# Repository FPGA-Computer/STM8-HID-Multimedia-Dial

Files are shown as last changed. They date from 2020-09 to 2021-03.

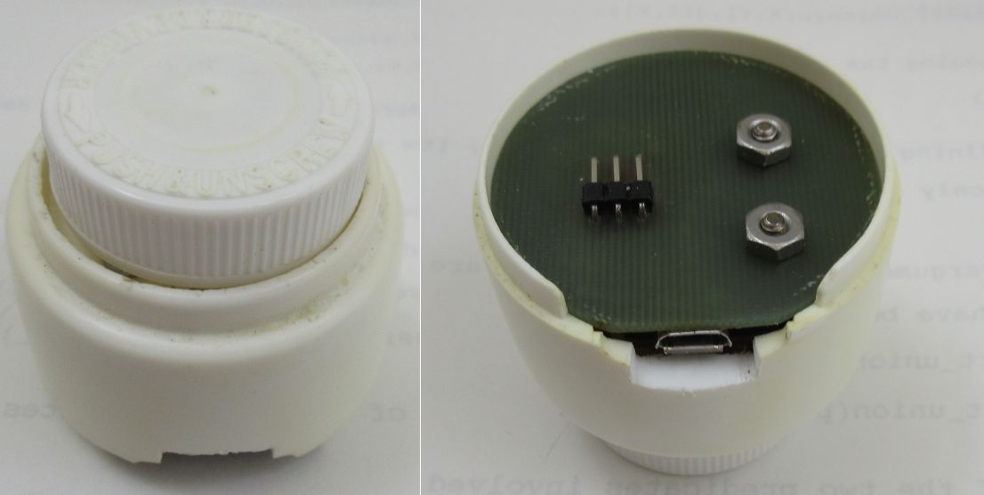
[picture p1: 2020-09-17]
hardware/Assembled.jpg

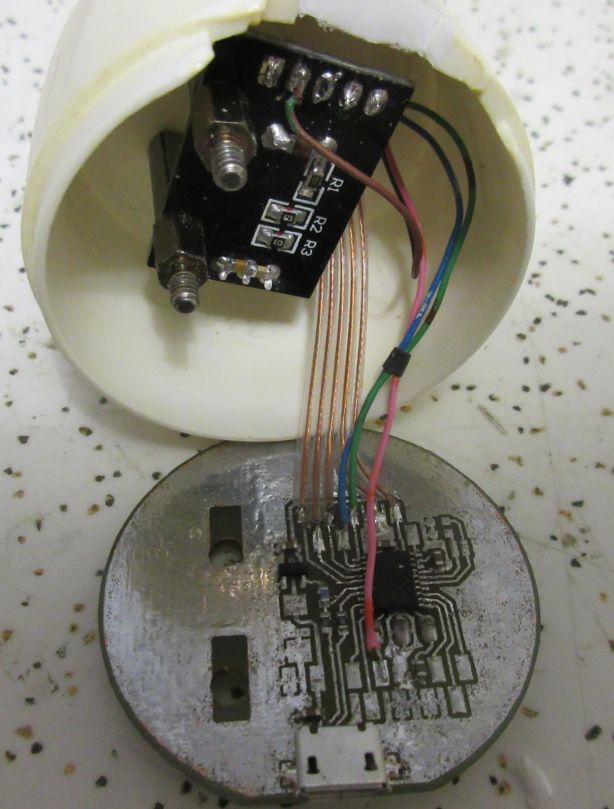
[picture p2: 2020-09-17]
hardware/wiring.jpg

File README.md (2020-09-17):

# STM8 HID Multimedia Dial

This is a USB HID with a rotatory encoder. This is used to supplement old keyboard layouts by providing a more natural alternative.

Details: https://hw-by-design.blogspot.com/2018/07/hid-multimedia-dial.html

This is a port of my [HID Dial project](https://github.com/FPGA-Computer/HID-Multimedia-Dial) (ATMega8) to STM8S003 using STM8 VUSB library.

# STM8 VUSB

The firmware only USB stack is an unofficial fork from STM8S-VUSB-KEYBOARD at https://github.com/BBS215/STM8S-VUSB-KEYBOARD

- Works with current special edition of Cosmic C (4.4.10) and current version of STVD (4.3.12)

- USB stack logic is modified for this tech demo. HID is now working.

- Code reformatted/refractored.  Using my own IRQ files for STM8S003 for a much cleaner organization. Some code logic changed.

- No longer need a separate GPIO for the 1.5K pull up to connect/disconnect USB.  See schematic.

- Device library calls have been changed to bare metal to minimized dependancy and reduce code size.  stm8s_flash.c is the only library needed.

Note: 

The USB stack calibrates the HSI clock while connected to the PC. The calibration is store in EEPROM. It can take a couple of minutes the first time before it functions correctly.

Timer 1 is used by the USB stack for filtering and interrupt. It is not actually used for counting.

Install a 10K into R1 and 3 0.1uF capacitors to the Rotary Encoder module (made in China).

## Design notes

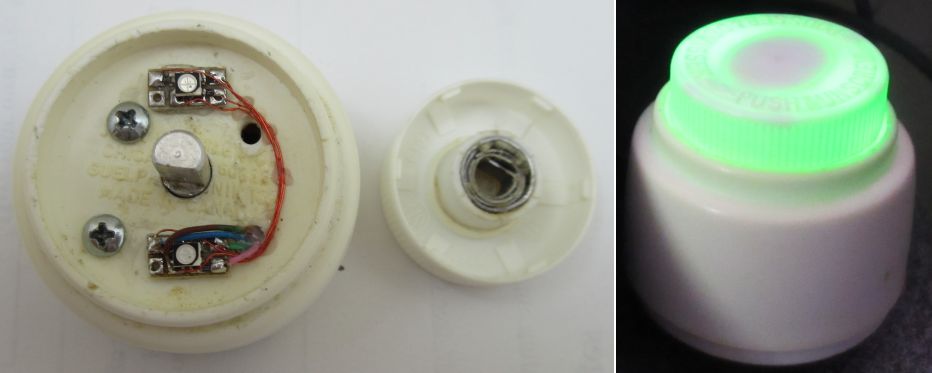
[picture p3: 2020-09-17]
hardware/Dial.jpg

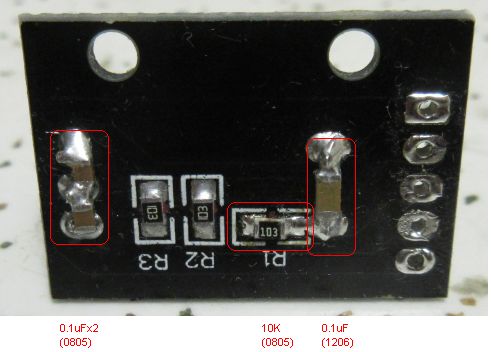
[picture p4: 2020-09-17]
hardware/Rotary encoder.jpg

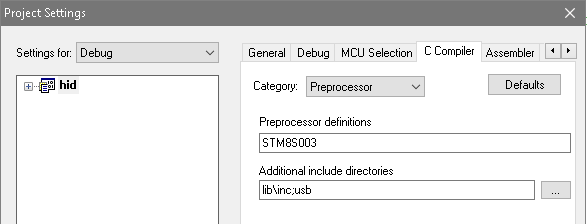
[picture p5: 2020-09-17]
firmware/Compiler setting.png

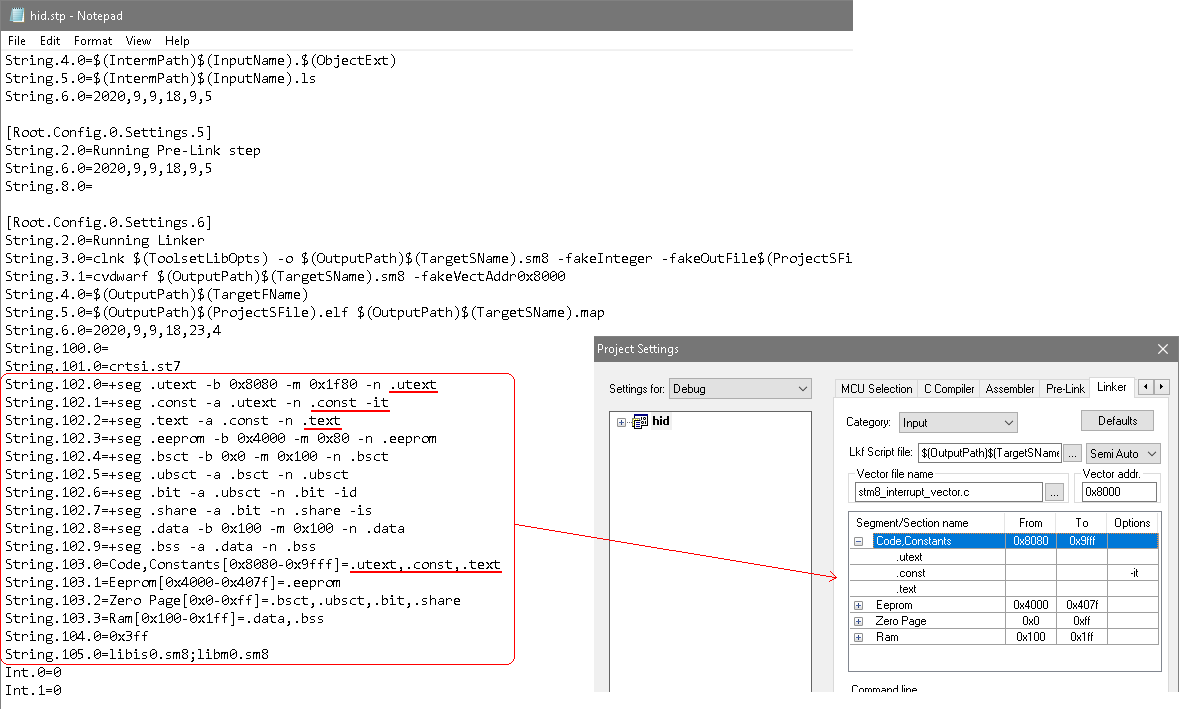
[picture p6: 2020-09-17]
firmware/linker setting.png

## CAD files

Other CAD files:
firmware/hid.stp

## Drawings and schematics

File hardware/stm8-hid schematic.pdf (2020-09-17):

A

A

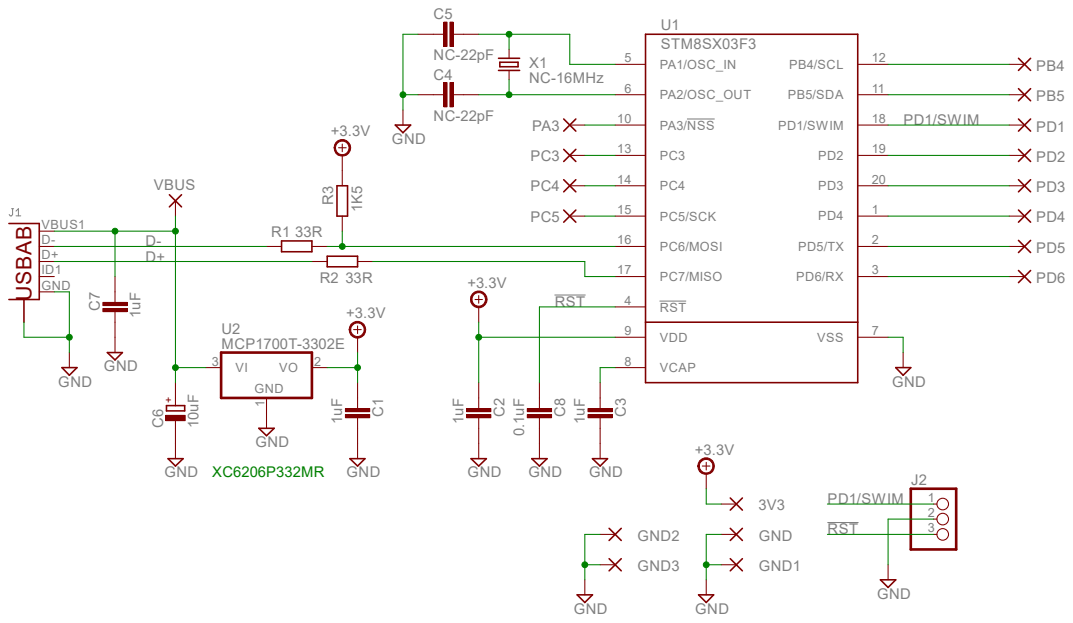
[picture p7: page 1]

D+ D- VBUS1 GND | D-

ID1 | | +3.3V RST

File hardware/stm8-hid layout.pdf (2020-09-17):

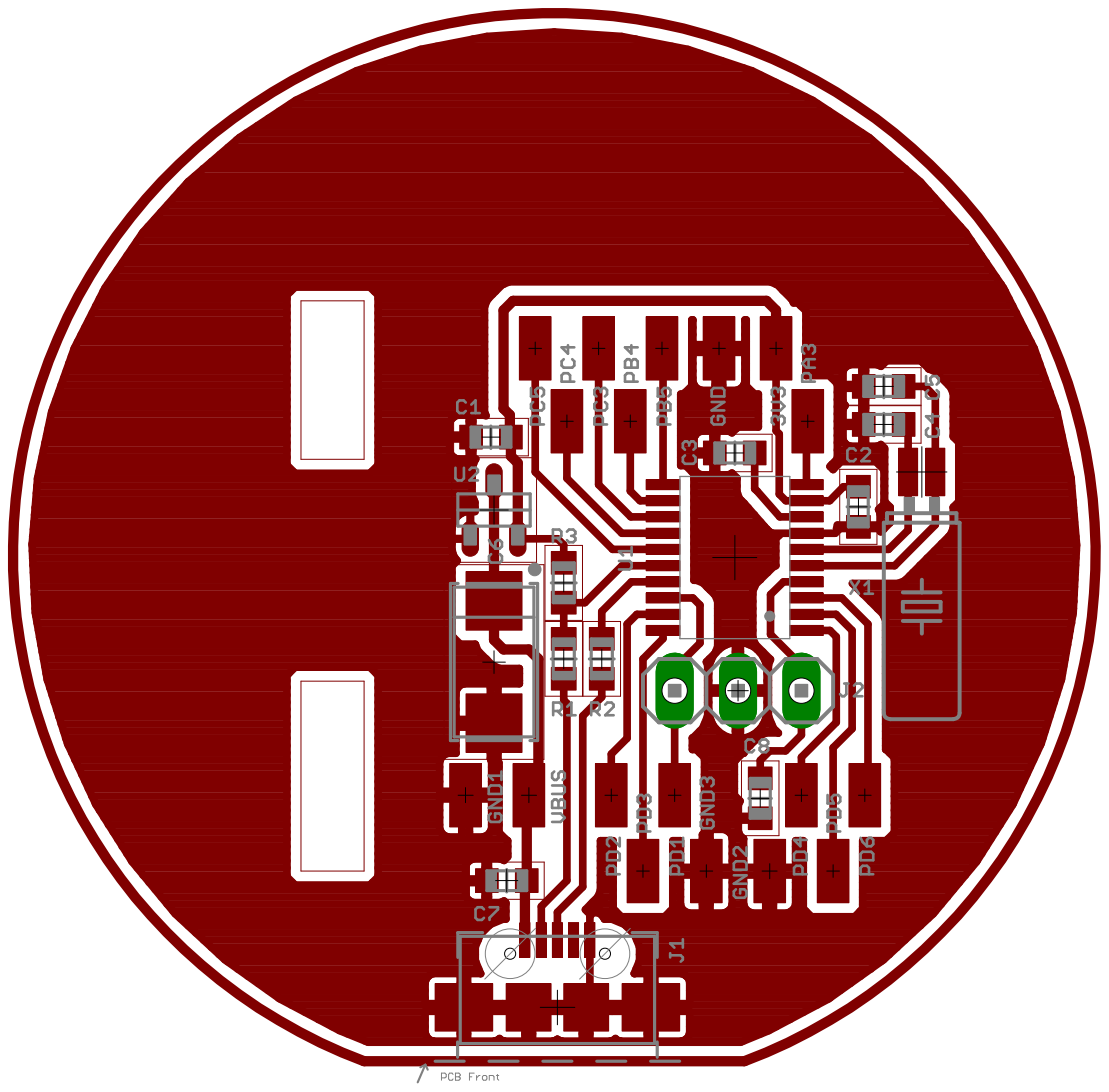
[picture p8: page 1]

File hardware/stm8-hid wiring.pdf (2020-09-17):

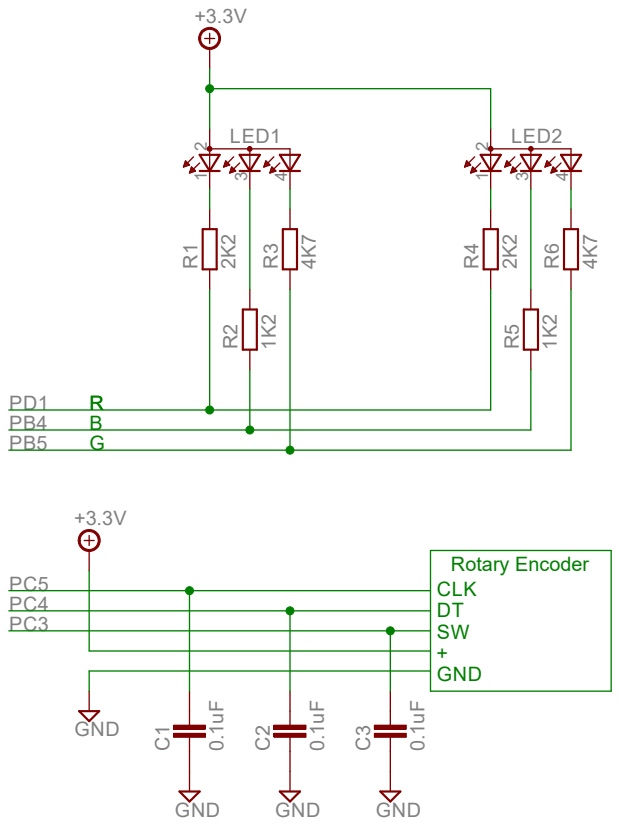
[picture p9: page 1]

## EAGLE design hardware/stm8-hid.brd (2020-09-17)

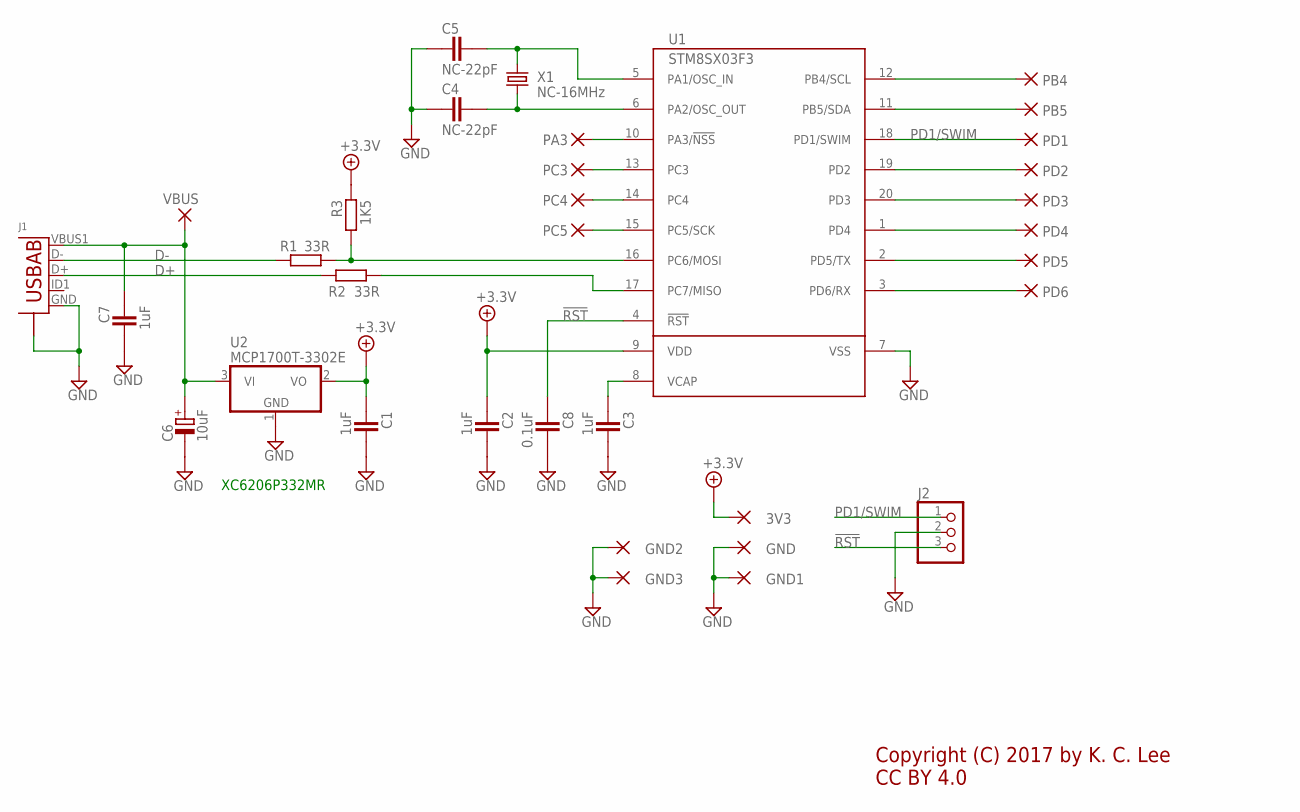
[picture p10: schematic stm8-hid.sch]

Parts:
3V3: SMD2; SMD1,27-2,54
C1, C2, C3: 1uF; CAPC1608X92N; PARTNO 1uF X7R 0603
C4, C5: NC-22pF; CAPC1608X92N; PARTNO 22pF 0603
C6: 10uF; CAPMP6032X280N; PARTNO 1uF X7R 0603
C7: 1uF; CAPC1608X92N; PARTNO NC 0805
C8: 0.1uF; CAPC1608X92N; PARTNO 1uF X7R 0603
GND, GND1, GND2, GND3: SMD2; SMD1,27-2,54
J1: USB-ABBG-ORG; USB-AB-MICRO-SMD_V03_SMT
J2: PINHD-1X3_2.54; 1X03
PA3: SMD2; SMD1,27-2,54
PB4, PB5: SMD2; SMD1,27-2,54
PC3, PC4, PC5: SMD2; SMD1,27-2,54
PD1, PD2, PD3, PD4, PD5, PD6: SMD2; SMD1,27-2,54
R1, R2: 33R; RESC1608X55N; PARTNO 47R 0603
R3: 1K5; RESC1608X55N; PARTNO 1K5 0603
U1: STM8SX03F3; TSSOP20
U2: MCP1700T-3302E; SOT95P280X135-3N; PARTNO MCP1700T-3302E/TT
VBUS: SMD2; SMD1,27-2,54; PARTNO Breakout
X1: NC-16MHz; TC38H; PARTNO 16MHz Crystal TC26

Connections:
!RST: C8.1, J2.3, U1.4 (!RST)
+3.3V: 3V3.1, C1.1, C2.1, R3.1, U1.9 (VDD), U2.2 (VO)
D+: J1.D+, R2.1
D-: J1.D-, R1.1
GND: C1.2, C2.2, C3.2, C4.1, C5.1, C6.-, C7.2, C8.2, GND.1, GND1.1, GND2.1, GND3.1, J1.GND, J1.S1 (S), J1.S2 (S), J1.S3 (S), J1.S4 (S), J2.2, U1.7 (VSS), U2.1 (GND)
unnamed: C3.1, U1.8 (VCAP)
unnamed: R2.2, U1.17 (PC7/MISO)
unnamed: R1.2, R3.2, U1.16 (PC6/MOSI)
unnamed: C4.2, U1.6 (PA2/OSC_OUT), X1.2
unnamed: C5.2, U1.5 (PA1/OSC_IN), X1.1
unnamed: PC5.1, U1.15 (PC5/SCK)
unnamed: PC4.1, U1.14 (PC4)
unnamed: PC3.1, U1.13 (PC3)
unnamed: PB4.1, U1.12 (PB4/SCL)
unnamed: PB5.1, U1.11 (PB5/SDA)
unnamed: PD2.1, U1.19 (PD2)
unnamed: PD3.1, U1.20 (PD3)
unnamed: PD4.1, U1.1 (PD4)
unnamed: PD5.1, U1.2 (PD5/TX)
unnamed: PD6.1, U1.3 (PD6/RX)
unnamed: PA3.1, U1.10 (PA3/!NSS)
PD1/SWIM: J2.1, PD1.1, U1.18 (PD1/SWIM)
VBUS: C6.+, C7.1, J1.VBUS1 (VBUS), U2.3 (VI), VBUS.1

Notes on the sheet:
Copyright (C) 2017 by K. C. Lee CC BY 4.0
XC6206P332MR

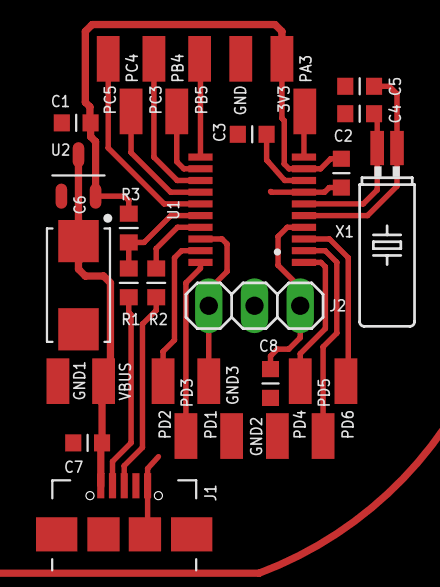
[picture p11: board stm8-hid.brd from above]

Board: 2 copper layers, 34 parts (0 on the bottom side), 23 nets.

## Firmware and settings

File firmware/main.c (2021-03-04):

#include "main.h"
#include "usb.h"
#include "hardware.h"

/*
	USB_EP0_RxReady_callback is pre-assigned for data processing,
	EP0 in the Data stage process.
*/

void USB_EP0_RxReady_callback(uint8_t *p_data, uint8_t length)
{
}

/*
USB_Class_Init_callback is called upon initiation
USB powered device.
*/
int8_t USB_Class_Init_callback(uint8_t dev_config)
{
	return 0;
}

/*
	USB_Class_DeInit_callback is called upon reset.
	USB powered device.
*/
int8_t USB_Class_DeInit_callback(void)
{
	return 0;
}

/*
	USB_Setup_Request_callback is called for processing USB requests,
	Not included in the standard USB stack.
*/

int8_t USB_Setup_Request_callback(t_USB_SetupReq *p_req)
{	
	// HID Class GetReport
  if (((p_req->bmRequest&USB_REQ_TYPE_MASK)==USB_REQ_TYPE_CLASS) && 
			(p_req->bRequest==HID_REQ_GET_REPORT))
	{
		USB_Send_Data(NULL,0,0); 
		return 0;
	}
	
	return -1;
}

/*
	USB_EP1_RxReady_callback is pre-assigned for data processing,
  Pins EP1. In this example, it is not used.
*/
void USB_EP1_RxReady_callback(uint8_t *p_data, uint8_t length)
{
	// Nothing. Really.
}

/// MAIN ///////////////////////////////////////////////////

void main(void)
{
	uint8_t counter = TIM4_CNTMAX;
	
	Init_Hardware();

	while(1)
	{
		USB_loop(); // A "quick" USB loop for processing requests
		HID_Task();

		if (TIM4->SR1 && TIM4_SR1_UIF)	// poll for TIM4 update
		{ 
			// clear update flag
			TIM4->SR1 = (uint8_t) ~TIM4_SR1_UIF;
			
			if (counter)
			{
				counter--;
				
				if(!counter)
				{
					// 100Hz call at different clock phase
					Encoder_Task();				
					Encoder_Switch_Task();
				}			
			}
			else
			{	// 100 Hz call
				USB_slow_loop(); // "slow" USB loop for setting HSI generator and EP1 watchdog
				counter = TIM4_CNTMAX;		
			}
		}
	}
}

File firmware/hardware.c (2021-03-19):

/*
 * hardware.c
 *
 * Created: August 30, 2019, 6:35:08 PM
 *  Author: K. C. Lee
 * Copyright (c) 2016 by K. C. Lee
 
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
 If not, see http://www.gnu.org/licenses/gpl-3.0.en.html 
 */ 

#include "hardware.h"
#include "usb.h"

uint8_t ReportIn[REPORT_SIZE]= {ID_CONSUMER }, Report_State = REPORT_RDY;

// Rotary encoder - positive count is clockwise
volatile int8_t Encoder_;
int8_t Encoder = 0;

void Init_Hardware(void)
{	
	Check_OPTION_BYTE();
	CLK->CKDIVR = 0; // HSIDIV = 0; CPUDIV = 0
		
	USB_disconnect();
	TIM4_Init();
	Encoder_Init();
	USB_Init();
	Delay(US_DELAY(90000));
	enableInterrupts();
	USB_connect();
}

#define IWDG_KEY_ENABLE 0xcc

void RESET_CHIP(void)
{
	IWDG->KR = IWDG_KEY_ENABLE; // Reset the CPU: Enable the watchdog and wait until it expires
	while(1);    // Wait until reset occurs from IWDG
}

void FLASH_Data_lock(uint8_t lock)
{
	if(lock)
		FLASH->IAPSR = 0;
	else
	{
		/* Warning: keys are reversed on data memory !!! */
    FLASH->DUKR = FLASH_RASS_KEY2;
    FLASH->DUKR = FLASH_RASS_KEY1;		
	}
}

void FLASH_Wait(void)
{
	while(!(uint8_t)(FLASH->IAPSR & (FLASH_IAPSR_EOP | FLASH_IAPSR_WR_PG_DIS)))
		/* wait*/;
}

void Check_OPTION_BYTE(void)
{
	uint8_t option_byte;

	if ((OPT->OPT2 != (uint8_t)(~OPT->NOPT2))||((OPT->OPT2 & AFR0) == 0)) 
	{ // check AFR0
		option_byte = OPT->OPT2|AFR0; 		// set AFR0 = 1 // PORT C[7..5] Alternate Function
		
		FLASH_Data_lock(0);
		FLASH->CR2 |= FLASH_CR2_OPT;
		FLASH->NCR2 &= (uint8_t)(~FLASH_NCR2_NOPT);

		OPT->OPT2 = option_byte;
		FLASH_Wait();

		OPT->NOPT2 = (uint8_t)(~option_byte);
		FLASH_Wait();
		
		// Disable write access to option bytes
		FLASH->CR2 &= (uint8_t)(~FLASH_CR2_OPT);
		FLASH->NCR2 |= FLASH_NCR2_NOPT;

		FLASH_Data_lock(1);
    RESET_CHIP();
	}
	
	if ((OPT->OPT3 != (uint8_t)(~OPT->NOPT3))||((OPT->OPT3 & HSITRIM) == 0)) 
	{ // check HSITRIM
		option_byte = OPT->OPT3|HSITRIM;			// 4 bit on-the-fly trimming
		
		FLASH_Data_lock(0);
		FLASH->CR2 |= FLASH_CR2_OPT;
		FLASH->NCR2 &= (uint8_t)(~FLASH_NCR2_NOPT);

		OPT->OPT3 = option_byte;
		FLASH_Wait();

		OPT->NOPT3 = (uint8_t)(~option_byte);
		FLASH_Wait();
		
		// Disable write access to option bytes
		FLASH->CR2 &= (uint8_t)(~FLASH_CR2_OPT);
		FLASH->NCR2 |= FLASH_NCR2_NOPT;
		FLASH_Data_lock(1);
    RESET_CHIP();
	}
}

void TIM4_Init(void)
{
	TIM4->ARR = TIM4_RELOAD;
	TIM4->PSCR = TIM4_PRSC;
	// Counter Enable
	TIM4->CR1 = TIM4_CR1_CEN;
}

void LED(uint8_t Colour)
{	
	if(Colour & LED_RED)
		LED_R_PORT->ODR &= (uint8_t)~LED_R;
	else
		LED_R_PORT->ODR |= LED_R;
		
	if(Colour & LED_GREEN)
		LED_G_PORT->ODR &= (uint8_t)~LED_G;
	else
		LED_G_PORT->ODR |= LED_G;
		
	if(Colour & LED_BLUE)
		LED_B_PORT->ODR &= (uint8_t)~LED_B;
	else
		LED_B_PORT->ODR |= LED_B;
}

void Encoder_Init(void)
{
	EXTI->CR1 = EXTI_CR1;			// Rising and falling edges
	// Encoder GPIO interrupt mask
	ENC_PORT->CR2 |=  ENC_CLK;
	// pull up on Switch
	ENC_SW_PORT->CR1 |= ENC_SW;
	
	LED(LED_OFF);
	// Check for debugger
	if(!(RST->SR & RST_SR_SWIMF))
		LED_R_PORT->DDR |= LED_R;
	
	LED_G_PORT->DDR |= LED_G;
	LED_B_PORT->DDR |= LED_B;
}

/*
@far @interrupt void Encoder_IRQ(void)
{
	static uint8_t Encoder_Prev;
  uint8_t Enc_Status;
	
  Enc_Status = (ENC_PORT->IDR & (ENC_CLK|ENC_DIR));	
	
  if((Encoder_Prev == ENC_DIR) && (Enc_Status == ENC_CLK))
    Encoder_--;    
  else if((!Encoder_Prev) && (Enc_Status == (ENC_CLK|ENC_DIR)))
    Encoder_++;

  Encoder_Prev = Enc_Status;
}
*/

// optimized code
@far @interrupt void Encoder_IRQ(void)
{
  static uint8_t Enc_Status;
	
	Enc_Status = (Enc_Status<<2)|(ENC_PORT->IDR&(ENC_CLK|ENC_DIR));	
	
	if(Enc_Status == ((ENC_DIR<<2)|ENC_CLK))
    Encoder_--;
	else if(Enc_Status == (ENC_CLK|ENC_DIR))
    Encoder_++;
}

static uint8_t Switch_Status = SW_EDGE_MASK, Sw_Timer, Sw_State = SW_NONE, Enc_State = ENC_VOLUME;
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

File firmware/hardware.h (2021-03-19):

/*
 * hardware.h
 *
 * Created: October 31, 2019, 12:33:01 PM
 *  Author: K. C. Lee
 * Copyright (c) 2019 by K. C. Lee
 
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
 If not, see http://www.gnu.org/licenses/gpl-3.0.en.html 
 */ 

#ifndef __CSMC__
#define __CSMC__
#endif
#ifndef STM8S003
#define STM8S003
#endif

#ifndef HARDWARE_H_
#define HARDWARE_H_

#include "stm8s.h"
#include <stdio.h>

// STM8S003F3P6
enum _PA { PA1=0x02, PA2=0x04, PA3=0x08 };
enum _PB { PB4=0x10, PB5=0x20 };
enum _PC { PC3=0x08, PC4=0x10, PC5=0x20, PC6=0x40, PC7=0x80 };
enum _PD { PD1=0x02, PD2=0x04, PD3=0x08, PD4=0x10, PD5=0x20, PD6=0x40 };

#define GPIO(X)					((GPIO_TypeDef *)(X))

#define CPU_CLOCK				16000000UL
#define EE_Addr					0x4000

enum _OPT2 { AFR0 = 0x01, AFR1=0x02, AFR2=0x04, AFR3=0x08, AFR4=0x10, AFR5=0x20, AFR6=0x40, AFR7 = 0x80 };
enum _OPT3 { HSITRIM = 0x10, LSI_EN = 0x08, IWDG_HW = 0x04, WWDG_HW = 0x02, WWDG_HALT = 0x01 };

#define FLASH_RASS_KEY1 ((uint8_t)0x56) /*!< First RASS key */
#define FLASH_RASS_KEY2 ((uint8_t)0xAE)

#define TIM4_PRSC				7
#define TIM4_FREQ				500
#define TIM4_Slow				100
#define TIM4_RELOAD			(CPU_CLOCK/(1<<TIM4_PRSC)/TIM4_FREQ)
#define TIM4_CNTMAX			(TIM4_FREQ/TIM4_Slow)

#define LED_R_PORT			GPIOD
#define LED_R						PD1
#define LED_G_PORT			GPIOB
#define LED_G						PB5
#define LED_B_PORT			GPIOB
#define LED_B						PB4

enum _LED
{
	LED_OFF = 0x00,	LED_RED = 0x01, LED_GREEN = 0x02, LED_BLUE = 0x04,
	LED_YELLOW = LED_RED|LED_GREEN, 
	LED_MAGENTA = LED_RED|LED_BLUE,
	LED_AQUA = LED_GREEN|LED_BLUE, 
	LED_WHITE = LED_RED|LED_GREEN|LED_BLUE
};

#define ENC_PORT				GPIOC
#define ENC_CLK					PC5
#define ENC_DIR					PC4
#define ENC_SW_PORT			GPIOC
#define ENC_SW					PC3

#define EXTI_CR1				0x30

extern volatile uint8_t TIM4_Update_Flag;


// Delays in us.  The delay has been calibrated for 16MHz
// Maximum delay is about 100ms (16-bit)

#define DELAY_TWEAK			0.63
#define US_DELAY(X)			((uint16_t)(X*DELAY_TWEAK))

// Switch status is a shift register that shift left every 16.38ms
#define SW_RISING_EDGE        0x07      // 00000111  <- turned high for 49ms 
#define SW_FALLING_EDGE       0xf8      // 11111000  <- turned low for 49ms 
#define SW_EDGE_MASK          0x0f
#define SW_DEBOUNCE_MASK      0x03

#define SW_AT_MAKE            ((Switch_Status & SW_EDGE_MASK) == (SW_FALLING_EDGE & SW_EDGE_MASK))
#define SW_AT_BREAK           ((Switch_Status & SW_EDGE_MASK) == (SW_RISING_EDGE & SW_EDGE_MASK))
#define SW_MAKE               ((Switch_Status & SW_DEBOUNCE_MASK) == (SW_FALLING_EDGE & SW_DEBOUNCE_MASK))
#define SW_BREAK              ((Switch_Status & SW_DEBOUNCE_MASK) == (SW_RISING_EDGE & SW_DEBOUNCE_MASK))

#define ms_TO_TICKS(X)				((X)/10)

#define TIMER_DBL_BREAK       ms_TO_TICKS(250)
#define TIMER_CLICK_MAKE		  ms_TO_TICKS(150)
#define TIMER_LONG            ms_TO_TICKS(400)

enum SW_STATE
{
  SW_NONE, SW_PRESS, SW_DBL_BREAK, SW_DBL_CLICK, SW_HOLD, SW_BREAK_WAIT
 };

enum ENC_STATES
{
  ENC_VOLUME, ENC_PLAYCTRL
 };

#define ENC_LAST  ENC_PLAYCTRL
#define ENC_FIRST ENC_VOLUME 

#define REPORT_SIZE		    2

enum REPORT_ID
{
  ID_CONSUMER = 0x01
 };

#define ENC_LAST  ENC_PLAYCTRL
#define ENC_FIRST ENC_VOLUME 

enum EndPoint
{
	EP0, EP1
};

enum REPORT_STATE
{
  REPORT_RDY, REPORT_CMD_RELEASE, REPORT_CMD
 };

enum REPORT_BITMAP
{
  Cmd_Next_Track =0x01, Cmd_Prev_Track = 0x02, Cmd_Stop = 0x04, Cmd_Play_Pause = 0x08, 
  Cmd_Mute = 0x10, Cmd_Volume_Up = 0x20, Cmd_Volume_Down = 0x40
 };

void Init_Hardware(void);
void RESET_CHIP(void);
void Check_OPTION_BYTE(void);
void TIM4_Init(void);
void Delay(uint16_t t);
void LED(uint8_t Colour);
void Encoder_Init(void);
void Encoder_Switch_Task(void);
void Encoder_Task(void);
void HID_Task(void);
void FLASH_Data_lock(uint8_t lock);
void FLASH_Wait(void);
#endif

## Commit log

2021-03-04 fix long wait for USB device recognization
    [main.c, usb-config.h, usb.c]
2021-03-08 Removed library - smaller code
    [hid.stp]

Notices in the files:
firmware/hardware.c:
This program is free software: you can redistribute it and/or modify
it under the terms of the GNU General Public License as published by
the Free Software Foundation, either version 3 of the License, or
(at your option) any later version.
